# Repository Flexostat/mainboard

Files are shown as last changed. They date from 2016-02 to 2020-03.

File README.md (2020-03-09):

# mainboard
The main PCB that runs the Flexostat

<br />This work is licensed under a <a rel="license" href="http://creativecommons.org/licenses/by/4.0/">Creative Commons Attribution 4.0 International License</a>.

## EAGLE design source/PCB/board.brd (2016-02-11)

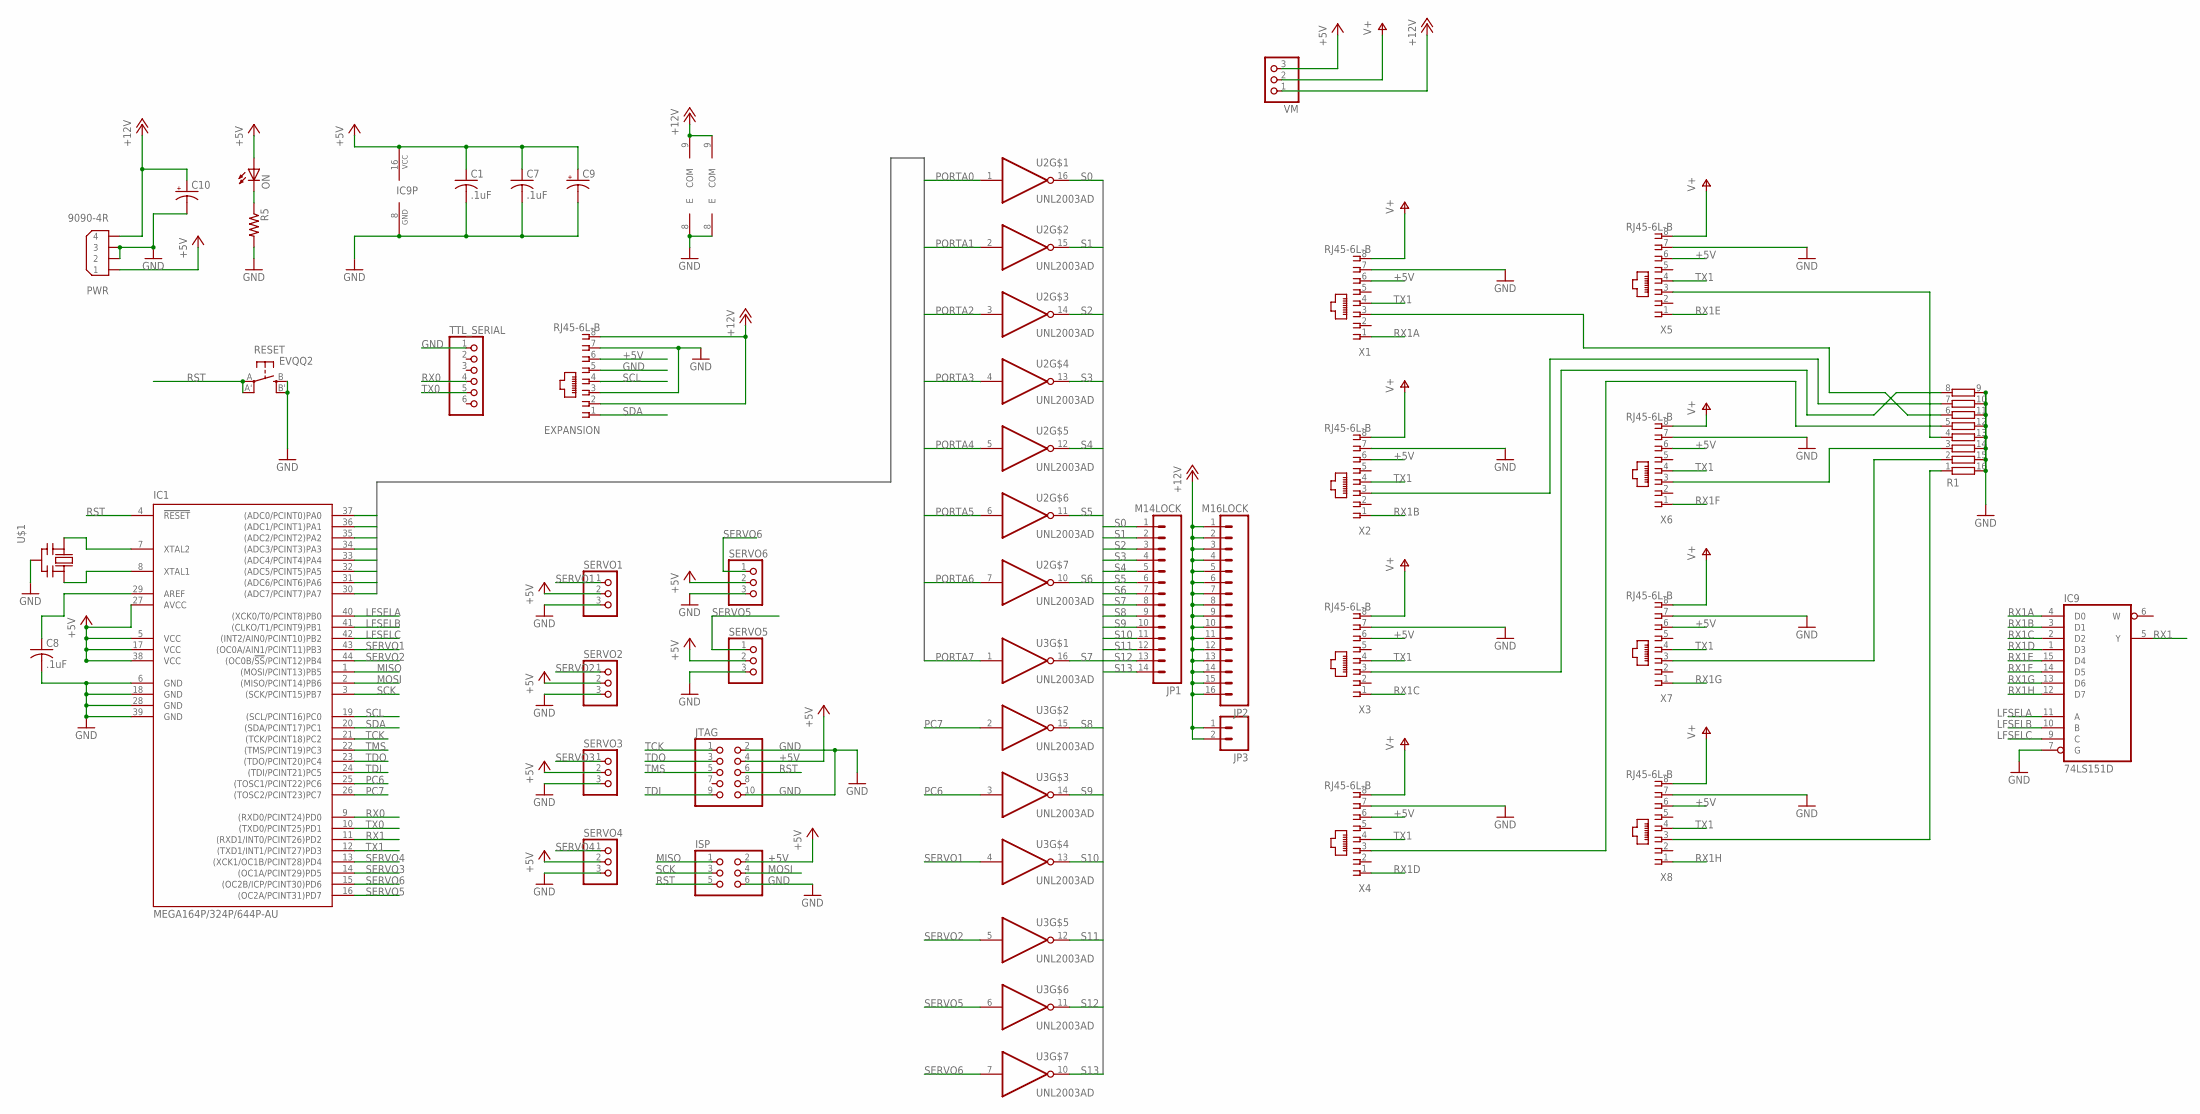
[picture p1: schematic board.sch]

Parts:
C1, C7, C8: .1uF; C0805
C9, C10: CPOL-USE2.5-7; E2,5-7
EXPANSION: RJ45-6L-B; RJ45-NO-SHIELD
IC1: MEGA164P/324P/644P-AU; TQFP44
IC9: 74LS151D; SO16
ISP: PINHD-2X3; 2X03
JP1: M14LOCK; 1X14_LOCK
JP2: M16LOCK; 1X16_LOCK
JP3: M02PTH; 1X02
JTAG: PINHD-2X5; 2X05
ON: LEDCHIPLED_0805; CHIPLED_0805
PWR: 9090-4R
R1: 2NBS16-8; SO16
R5: R-US_R0805; R0805
RESET: EVQQ2; EVQ-Q2
SERVO1, SERVO2, SERVO3, SERVO4, SERVO5, SERVO6: PINHD-1X3; 1X03
TTL_SERIAL: PINHD-1X6; 1X06
U2, U3: UNL2003AD; SO16
U$1: CERMOSCILL-CSTCRG; CSTCR-G
VM: PINHD-1X3; 1X03
X1, X2, X3, X4, X5, X6, X7, X8: RJ45-6L-B; RJ45-NO-SHIELD

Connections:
+5V: C1.1, C7.1, C9.+, EXPANSION.6, IC1.5 (VCC), IC1.17 (VCC), IC1.27 (AVCC), IC1.38 (VCC), IC9.16 (VCC), ISP.2, JTAG.4, ON.A, PWR.1, SERVO1.2, SERVO2.2, SERVO3.2, SERVO4.2, SERVO5.2, SERVO6.2, VM.3, X1.6, X2.6, X3.6, X4.6, X5.6, X6.6, X7.6, X8.6
+12V: C10.+, EXPANSION.2, EXPANSION.8, JP2.1, JP2.2, JP2.3, JP2.4, JP2.5, JP2.6, JP2.7, JP2.8, JP2.9, JP2.10, JP2.11, JP2.12, JP2.13, JP2.14, JP2.15, JP2.16, JP3.1, JP3.2, PWR.4, U2.9 (COM), U3.9 (COM), VM.1
GND: C1.2, C7.2, C8.2, C9.-, C10.-, EXPANSION.3, EXPANSION.5, EXPANSION.7, IC1.6 (GND), IC1.18 (GND), IC1.28 (GND), IC1.39 (GND), IC9.7 (G), IC9.8 (GND), ISP.6, JTAG.2, JTAG.10, PWR.2, PWR.3, R1.9, R1.10, R1.11, R1.12, R1.13, R1.14, R1.15, R1.16, R5.2, RESET.B (S), RESET.B' (S1), SERVO1.3, SERVO2.3, SERVO3.3, SERVO4.3, SERVO5.3, SERVO6.3, TTL_SERIAL.1, U2.8 (E), U3.8 (E), U$1.2 (GND), X1.7, X2.7, X3.7, X4.7, X5.7, X6.7, X7.7, X8.7
LFSELA: IC1.40 ((XCK0/T0/PCINT8)PB0), IC9.11 (A)
LFSELB: IC1.41 ((CLKO/T1/PCINT9)PB1), IC9.10 (B)
LFSELC: IC1.42 ((INT2/AIN0/PCINT10)PB2), IC9.9 (C)
MISO: IC1.1 ((MOSI/PCINT13)PB5), ISP.1
MOSI: IC1.2 ((MISO/PCINT14)PB6), ISP.4
unnamed: IC1.7 (XTAL2), U$1.1 (IN)
unnamed: IC1.8 (XTAL1), U$1.3 (OUT)
unnamed: R1.1, X8.3
unnamed: R1.6, X1.3
unnamed: R1.7, X2.3
unnamed: R1.8, X3.3
unnamed: R1.5, X4.3
unnamed: R1.4, X5.3
unnamed: R1.3, X6.3
unnamed: R1.2, X7.3
unnamed: C8.1, IC1.29 (AREF)
unnamed: ON.C, R5.1
PC6: IC1.25 ((TOSC1/PCINT22)PC6), U3.3 (I)
PC7: IC1.26 ((TOSC2/PCINT23)PC7), U3.2 (I)
PORTA0: IC1.37 ((ADC0/PCINT0)PA0), U2.1 (I)
PORTA1: IC1.36 ((ADC1/PCINT1)PA1), U2.2 (I)
PORTA2: IC1.35 ((ADC2/PCINT2)PA2), U2.3 (I)
PORTA3: IC1.34 ((ADC3/PCINT3)PA3), U2.4 (I)
PORTA4: IC1.33 ((ADC4/PCINT4)PA4), U2.5 (I)
PORTA5: IC1.32 ((ADC5/PCINT5)PA5), U2.6 (I)
PORTA6: IC1.31 ((ADC6/PCINT6)PA6), U2.7 (I)
PORTA7: IC1.30 ((ADC7/PCINT7)PA7), U3.1 (I)
RST: IC1.4 (!RESET), ISP.5, JTAG.6, RESET.A, RESET.A' (P1)
RX0: IC1.9 ((RXD0/PCINT24)PD0), TTL_SERIAL.4
RX1: IC1.11 ((RXD1/INT0/PCINT26)PD2), IC9.5 (Y)
RX1A: IC9.4 (D0), X1.1
RX1B: IC9.3 (D1), X2.1
RX1C: IC9.2 (D2), X3.1
RX1D: IC9.1 (D3), X4.1
RX1E: IC9.15 (D4), X5.1
RX1F: IC9.14 (D5), X6.1
RX1G: IC9.13 (D6), X7.1
RX1H: IC9.12 (D7), X8.1
S0: JP1.1, U2.16 (O)
S1: JP1.2, U2.15 (O)
S2: JP1.3, U2.14 (O)
S3: JP1.4, U2.13 (O)
S4: JP1.5, U2.12 (O)
S5: JP1.6, U2.11 (O)
S6: JP1.7, U2.10 (O)
S7: JP1.8, U3.16 (O)
S8: JP1.9, U3.15 (O)
S9: JP1.10, U3.14 (O)
S10: JP1.11, U3.13 (O)
S11: JP1.12, U3.12 (O)
S12: JP1.13, U3.11 (O)
S13: JP1.14, U3.10 (O)
SCK: IC1.3 ((SCK/PCINT15)PB7), ISP.3
SCL: EXPANSION.4, IC1.19 ((SCL/PCINT16)PC0)
SDA: EXPANSION.1, IC1.20 ((SDA/PCINT17)PC1)
SERVO1: IC1.43 ((OC0A/AIN1/PCINT11)PB3), SERVO1.1, U3.4 (I)
SERVO2: IC1.44 ((OC0B/!SS!/PCINT12)PB4), SERVO2.1, U3.5 (I)
SERVO3: IC1.14 ((OC1A/PCINT29)PD5), SERVO3.1
SERVO4: IC1.13 ((XCK1/OC1B/PCINT28)PD4), SERVO4.1
SERVO5: IC1.16 ((OC2A/PCINT31)PD7), SERVO5.1, U3.6 (I)
SERVO6: IC1.15 ((OC2B/ICP/PCINT30)PD6), SERVO6.1, U3.7 (I)
TCK: IC1.21 ((TCK/PCINT18)PC2), JTAG.1
TDI: IC1.24 ((TDI/PCINT21)PC5), JTAG.9
TDO: IC1.23 ((TDO/PCINT20)PC4), JTAG.3
TMS: IC1.22 ((TMS/PCINT19)PC3), JTAG.5
TX0: IC1.10 ((TXD0/PCINT25)PD1), TTL_SERIAL.5
TX1: IC1.12 ((TXD1/INT1/PCINT27)PD3), X1.4, X2.4, X3.4, X4.4, X5.4, X6.4, X7.4, X8.4
V+: VM.2, X1.8, X2.8, X3.8, X4.8, X5.8, X6.8, X7.8, X8.8

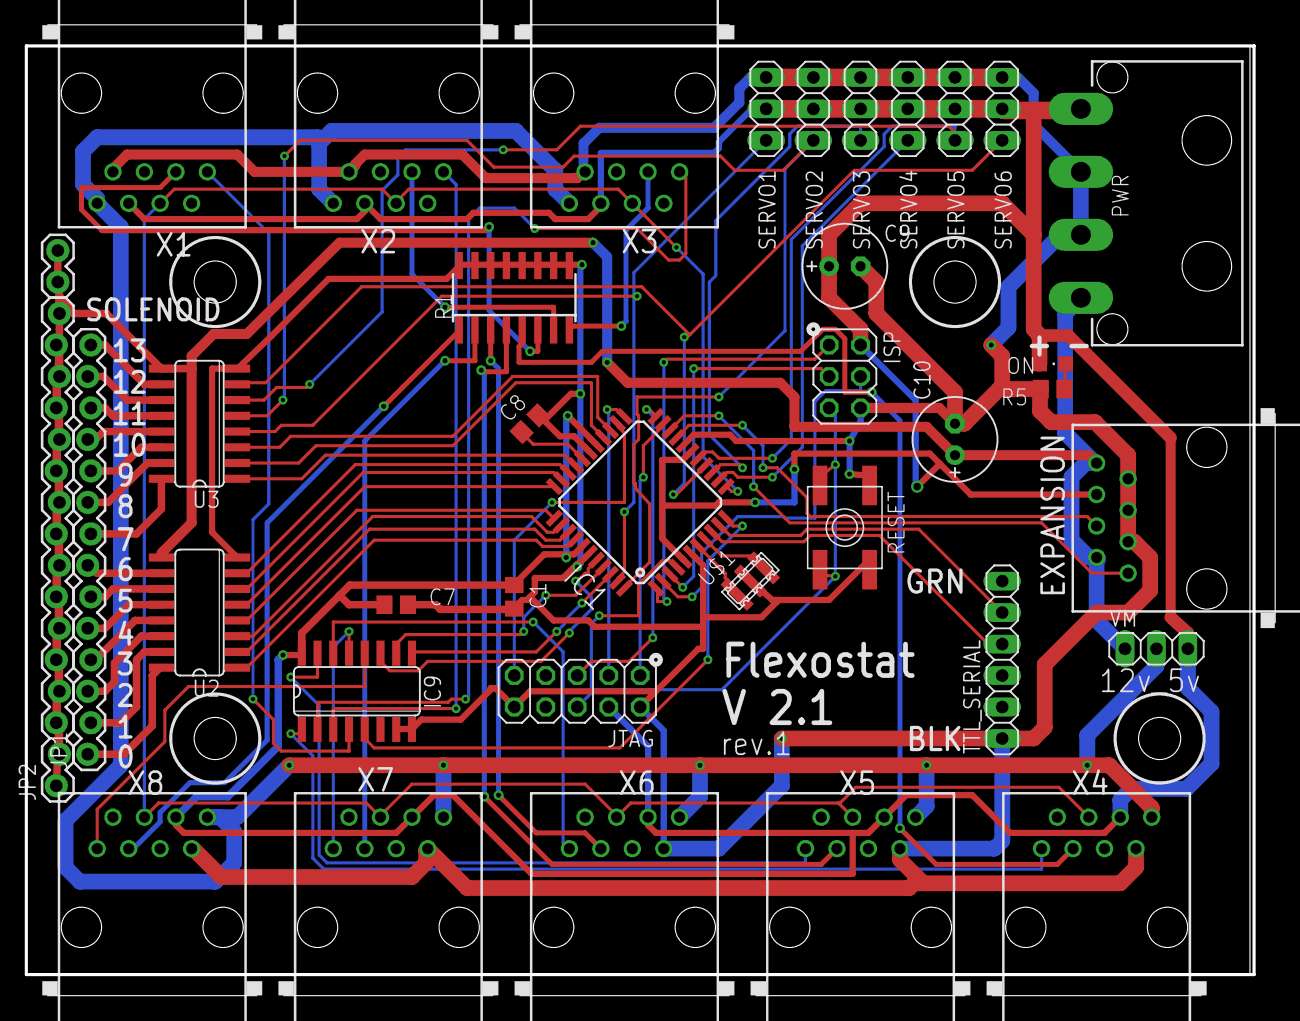
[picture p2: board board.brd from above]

Board: 2 copper layers, 100.8 x 78.3 mm, 37 parts (0 on the bottom side), 71 nets.

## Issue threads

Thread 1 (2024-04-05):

Add mainboard BOM

KarlGerhardt, 2024-04-05:
Hi Chris,

Do you have a BOM for the mainboard? Is it the same as the components listed [here](https://depts.washington.edu/soslab/turbidostat/pmwiki/pmwiki.php?n=ConstructionManual.ElectronicsMainBoard)?

As an aside, any plans to upload the Fluorostat designs/assembly instructions?

Cheers,
Karl

christakahashi, 2024-04-08:
I believe so.  I don't recall making substantial changes.

KarlGerhardt, 2024-04-10:
Thanks Chris. I'll compile one as I go along. Is this part listed anywhere? I think it was introduced with v2.1.

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

christakahashi, 2024-04-10:
oh thats just 3 0.1" header pins with a "jumper" on top.  If you're shopping for a jumper they're called a "shunt" on places like digikey.  you can also get a ton of them on places like amazon, ebay, etc.

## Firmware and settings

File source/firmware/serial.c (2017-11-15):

#include "serial.h"
#include "pwm.h"
#include "i2c.h"
#include <avr/io.h>
#include <avr/interrupt.h>
#include <stdlib.h>
#include <util/atomic.h>

#define DISABLE_TX_INT()  UCSR0B &= ~(1<<UDRIE0);
#define ENABLE_TX_INT()  UCSR0B |= (1<<UDRIE0);

#define BLOCKING_TX

void comm_init();

#define NUM_CMD 6
command cmdlist[NUM_CMD];

volatile uint8_t rxbuf[RX_BUFFER_SIZE];
volatile uint8_t txbuf[TX_BUFFER_SIZE];
volatile uint8_t rxsp, rxlen;  //start pointer, data length 0=>empty
volatile uint8_t txsp, txlen; //start point, data length
//start pointer is start of valid data
volatile int8_t cmdflag;
volatile uint8_t pulse_time[9]= {0,0,0,0,0,0,0,0,0}; // for SPV pulse mode.
const uint8_t pulse_time_len = (sizeof(pulse_time)/sizeof(pulse_time[0]));

//init serial 8N1
void usart_init() {
	comm_init();
	cmdflag = 0;
	rxsp = 0;
	rxlen = 0;
	txsp = 0;
	txlen = 0;
	//setup USART clock
	UBRR0 = UBRR_VAL;
	//UCSR0A = 0; //default value good.
	//enable TX and RX
	//enable RX complete interrupt and USART DR empty
	UCSR0B = (1<<RXEN0)|(1<<TXEN0)|(1<<RXCIE0)|(1<<UDRIE0);
	//8 data bits
	UCSR0C = 0x06;

	DDRD |= 0x02; //setup TX to be an output

	//ENABLE_TX_INT(); //already done

	//for PV
	PORTA = 0; //close all PVs
	DDRA = 0xFF; //outputs
	DDRC = 0x80 | 0x40; // SPV outputs

}

uint8_t get_tx_len(){
	return txlen;
}

ISR(USART0_RX_vect) {
	uint8_t data = UDR0;
	if (rxlen < RX_BUFFER_SIZE) {
		rxbuf[(rxsp + rxlen)%RX_BUFFER_SIZE] = data;
		rxlen++;
	}
	if (data == COMMAND_CHAR){
		cmdflag++;
	}
}

ISR(USART0_UDRE_vect) {
	if (txlen>0) {
		UDR0 = txbuf[txsp];
		txsp = (txsp+1)%TX_BUFFER_SIZE;
		txlen--;
	} else {
		DISABLE_TX_INT();
	}
}

//returns 0 if buffer overflow; nothing printed
//returns 1 success!
uint8_t print_char (uint8_t c) {
	uint8_t retval = 0;
#ifndef BLOCKING_TX
	ATOMIC_BLOCK(ATOMIC_RESTORESTATE)
	{
		if (txlen < TX_BUFFER_SIZE) {
			txbuf[(txsp + txlen)%TX_BUFFER_SIZE] = c;
			txlen++;
			ENABLE_TX_INT();
			retval = 1;
		}
	}
#else
	//Wait until the transmitter is ready

	while(!(UCSR0A & (1<<UDRE0)))
	{
		//Do nothing
	}

   //Now write the data to USART buffer

	UDR0=c;
	retval = 1;
#endif
	return retval;
}


//returns 0 if buffer overflow
//1 otherwise
uint8_t print_string (const uint8_t *s) {
	while (*s != 0) {
		if (print_char(*s)==0) {
			return 0;
		}
		s++;
	}
	return 1;
}

//returns 0 if buffer full
uint8_t print_ulong (uint32_t n) {
	uint8_t b[12];
	return print_string ((uint8_t*)ultoa(n,(char*)b,10));
}


//returns 0 if the buffer is empty
//only place in code that shrinks rxlen
uint8_t read_char () {
	uint8_t retval=0;
	ATOMIC_BLOCK(ATOMIC_RESTORESTATE)
	{
		if (rxlen>0) {
			retval = rxbuf[rxsp];
			rxlen--;
			rxsp = (rxsp+1)%RX_BUFFER_SIZE;
		}
	}
	return retval;
}


uint8_t* read_cmd(uint8_t* b) {
	uint8_t *rv = b;
	uint8_t temp;
	do {
		temp = read_char();
		*b = temp;
		b++;
	} while (temp != COMMAND_CHAR && temp != 0);
	--b;
	*b = 0; //null terminate.

	ATOMIC_BLOCK(ATOMIC_RESTORESTATE)
	{
		if (temp == COMMAND_CHAR && cmdflag>0) { //>0 check just in case.
			cmdflag--;
		} else {
			cmdflag = 0;
		}
	}
	return rv;
}

void pv_on(uint8_t t) {
  if (t < 8) {
    PORTA |= 0x01<<t; //open SPV t
  } else {    
    switch (t)
    {
    case 8:
      PORTC |= 0x80; //PortC7
      break;
    case 9:
      PORTC |= 0x40; //PortC6
      break;
    }
  }
}

void pv_off(uint8_t t) {
  if (t < 8) {
    PORTA &= ~(0x01<<t); //open SPV t
  } else {    
    switch (t)
    {
    case 8:
      PORTC &= ~0x80; //PortC7
      break;
    case 9:
      PORTC &= ~0x40; //PortC6
      break;
    }
  } 
}


/*****COMMAND PARSING******/
uint8_t pulse(uint32_t t) {
  //command: pulnmmm; 
  //    n is chamber number,
  //    mmm WITH leading zeros is pulse duration max 255;
  uint8_t duration = (uint8_t)(t&0x000000FF);
  uint8_t valve = (uint8_t)((t&0x0000FFFF)/1000);
  
  //compensate for closing the valve at 1 instead of zero. 
  if (duration < 255) {
	duration += 1; 
  }
  if ( valve < pulse_time_len ) {
    pulse_time[valve]= duration;
  } 
  return 0;
}

uint8_t pv_select(uint32_t t) {
	//i2c pv
	if (t>0 && t<9) {
		master_send_i2c(114, (uint8_t) (t-1+'0'));
	}
	
	//SPV
	PORTC &= 0x3F; //0011 1111
	if (t < 8) { 
		PORTA = 0x01<<t; //open SPV t
	} else {  
		PORTA = 0; //close all SPV on port A
		switch (t)
		{
		case 8:
			PORTC |= 0x80; //PortC7
			break;
		case 9:
			PORTC |= 0x40; //PortC6
			break;
		}
	} 

	//servo
	if (t<5) {  //if mux PV 1
		pwm_set(2,0);
		pwm_set(1,(uint16_t)t*45*20);
		pwm_set(6,0);
		pwm_set(5,(uint16_t)t*45*20);
	} else if (t<=8){
		pwm_set(1,0);
		pwm_set(2,(uint16_t)(t-4)*45*20);
		pwm_set(5,0);
		pwm_set(6,(uint16_t)(t-4)*45*20);
	}
	return 0;
}
uint8_t pv_close_all(uint32_t t) {
	//pv_select(0);
	pwm_set(1,0);
	pwm_set(2,0);
	pwm_set(5,0);
	pwm_set(6,0);
	PORTA = 0x00; //close all SPVs
	PORTC &= 0x3F; //close port C SPVs
	return 0;
}
uint8_t pump_move_a(uint32_t t) {
	pwm_set(3,(uint16_t)t*2);
	return 0;
}
uint8_t pump_move_b(uint32_t t) {
	pwm_set(4,(uint16_t)t*2);
	return 0;
}

void comm_init() {
	/////Select PV command
	cmdlist[0].str[0] = 's';
	cmdlist[0].str[1] = 'e';
	cmdlist[0].str[2] = 'l';
	cmdlist[0].str[3] = 0;
	cmdlist[0].args = 1;
	cmdlist[0].fn = &pv_select;
	/////close PV command
	cmdlist[1].str[0] = 'c';
	cmdlist[1].str[1] = 'l';
	cmdlist[1].str[2] = 'o';
	cmdlist[1].str[3] = 0;
	cmdlist[1].args = 0;
	cmdlist[1].fn = &pv_close_all;
	/////move pump a (depricated; backward compatable with older firmware)
	cmdlist[2].str[0] = 'p';
	cmdlist[2].str[1] = 'm';
	cmdlist[2].str[2] = 'v';
	cmdlist[2].str[3] = 0;
	cmdlist[2].args = 1;
	cmdlist[2].fn = &pump_move_a;
	/////move pump a
	cmdlist[3].str[0] = 'p';
	cmdlist[3].str[1] = 'm';
	cmdlist[3].str[2] = 'a';
	cmdlist[3].str[3] = 0;
	cmdlist[3].args = 1;
	cmdlist[3].fn = &pump_move_a;
  /////move pump b
	cmdlist[4].str[0] = 'p';
	cmdlist[4].str[1] = 'm';
	cmdlist[4].str[2] = 'b';
	cmdlist[4].str[3] = 0;
	cmdlist[4].args = 1;
	cmdlist[4].fn = &pump_move_b;
  /////pulnmmm; pulse chamber n for mmm time 
  cmdlist[5].str[0] = 'p';
  cmdlist[5].str[1] = 'u';
  cmdlist[5].str[2] = 'l';
  cmdlist[5].str[3] = 0;
  cmdlist[5].args = 1;
  cmdlist[5].fn = &pulse;
}

void parse_command() {
	uint8_t match;
	uint32_t arg = 0;
	uint8_t p[TX_BUFFER_SIZE];
	read_cmd(p);
	uint8_t *c = p;
	eatspace(c);

	//for each command
	for (uint8_t ind = 0; ind <NUM_CMD; ind++) {
		match = 1;
		//check the first 3 chars for a string match
		for (uint8_t ind2 = 0; ind2 <3; ind2++) {
			if (cmdlist[ind].str[ind2] != c[ind2]) {
				match = 0;
				break;
			}
		}
		//on match, get input and call func
		if (match) {
			c = c+3;
			if(cmdlist[ind].args == 1) {
				eatspace(c);
				arg = strtoul((char*)c,NULL,10);
			}
			cmdlist[ind].fn(arg);
		}
	}
	
	
}

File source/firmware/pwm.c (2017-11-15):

/*
 * pwm.c
 *
 * Created: 8/2/2011 3:10:29 PM
 *  Author: soslab
 */ 
#include <avr/io.h>
#include <avr/interrupt.h>
#include "pwm.h"
#include "serial.h"

volatile uint16_t time;

void pwm_init() {
	/*****PWM TIMER0******/
	DDRB |= 0x18;  //set OC0A and OC0B to outputs
	//clear on compare match, set on BOTTOM, FAST PWM
	TCCR0A = 1<<COM0A1 | 1<<COM0B1 | 1<<WGM01 | 1<<WGM00;
	TCCR0B = 0x05; //clock div 1024 

	//NOTES: Period ~= 16ms instead of 20ms... we'll see how that works
	//1 "count" in OCR reg is 64uS
	//10uS = 1degree
	//so, "center" is 23.4=23 counts
	//90 deg is 9.4=9 and 37.5=37
	//45deg is 16.4, 30.4
	OCR0A = 23; //center
	OCR0B = 23; //center
	
	
	/*****PWM TIMER1******/ 
	//this is for pwm channels 1 2 3
	//set as outputs
	DDRD |= 0x30;
	TCCR1A = 0xAA; // non inverting on all three channels, WGM1:0 = 0b10
	TCCR1B = 0x1A; // /8 prescalar, WGM3:2 = 0b11
	//roll over every 40000*8 cycles = 20ms period
	//this also implies that one count is 0.5uS
	ICR1 = 40000-1; 
	//set all PWM outputs to dead center
	OCR1A = 3000;//1500uS
	OCR1B = 3000;//1500uS
	TIMSK1 = 1<<TOV1; //turn on "overflow" interrupt for RTC
	
	/*****PWM TIMER2******/
	DDRD |= 0x80 | 0x40; // set OC2A and OC2B to outputs
	//clear on compare match, set on BOTTOM, FAST PWM
	TCCR2A = 1<<COM2A1 | 1<<COM2B1 | 1<<WGM21 | 1<<WGM20;  //CLEAR TO DISABLE
	TCCR2B = 0x04 | 0x02 | 0x01; //clock div 1024
	//NOTES: similar to timer 0
	OCR2A = 23;
	OCR2B = 23;
	
}


ISR (TIMER1_OVF_vect) {
	time = time+20; //interrupts happen every 20ms
  uint8_t ch=0;
  while (ch<pulse_time_len) {
    if (pulse_time[ch]>1) {  //if count is big keep valve open and continue on
      pulse_time[ch]--;
      pv_on(ch);
    } else if (pulse_time[ch] == 1){ //close on 1 count and do nothing on 0.
	  pulse_time[ch]--;
      pv_off(ch);
    }
	ch++;
  }
}

uint16_t millis() {
	//could make this more accurate by adding the timer value to time
	return time;
}

//set angle in units of 1/20th of a degree
//0_degrees is defined as all the way CCW (when facing the gear)
void pwm_set(uint8_t ch, uint16_t angle) {
	angle = angle + 600*2;
	if (angle > (600*2 + 180*20)) {
		angle = (600*2 + 180*20);
	}
	switch (ch) {
		case 1:
			OCR0A = (uint8_t)(angle/(2*64)); //angle/20/6.4
			break;
		case 2:
			OCR0B = (uint8_t)(angle/(2*64)); //angle/20/6.4
			break;
		case 3:
			OCR1A = angle;
			break;
		case 4:
			OCR1B = angle;
			break;
		case 5:
			OCR2A = (uint8_t)(angle/(2*64)); //angle/20/6.4
			break;
		case 6:
			OCR2B = (uint8_t)(angle/(2*64)); //angle/20/6.4
			break;
	}
	
}

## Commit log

2012-11-03 First commit of turbidostat 1.0 hardware and firmware files
    [board.brd, board.sch]
2014-05-13 updated directory structure and added binaries
    [board.GBL, board.GBO, board.GBP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]
2014-11-18 udptade to FLEXOSTAT V2.0
    [board.GBL, board.GBO, board.GBP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]
2014-11-18 fixed overlay layer. SPV numbers now line up with pins
    [board.GTO]
2015-04-14 small firmware but where chamber 8 wouldn't close under some circumstances
2015-04-17 basic i2c support
2015-04-17 i2c PV support
2016-01-24 v2.1 files
    [board.GBL, board.GBO, board.GBP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]
2016-02-11 updated design with mounting holes and wider traces
    [board.GBL, board.GBO, board.GBP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]

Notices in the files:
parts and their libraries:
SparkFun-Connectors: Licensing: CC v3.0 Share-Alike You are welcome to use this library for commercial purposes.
